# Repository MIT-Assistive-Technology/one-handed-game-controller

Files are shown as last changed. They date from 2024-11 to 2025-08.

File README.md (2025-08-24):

# :video_game: **One-Handed Game Controller (Left-Handed)**

## :memo: **Instructions Overview**

⭐ **Please refer to [this handout](https://docs.google.com/document/d/1R1JeNCjT1L_K-hidx_33zdM9vNTuleeNFn41tkV1ZXg/edit?usp=sharing) for detailed instructions and materials.**

1. Download files
2. 3D print files
4. Print/Order PCBs
5. Solder Electronic Components
6. Upload code to the Arduino
7. Assemble

## :mag_right: Problem Statement
**Modern game controllers do not accommodate for one-handed users.**

After a stroke or injury, a person may lose some function in their body. Recreational products for the public are often made with the assumption that a person has full control of their body, which means that after permanent injuries, a person may become limited in their choice of hobbies.

Our codesigner, Susan Bibbins, suffers from chronic pain from fibromyalgia and has limited function in her right hand. She always wanted to play video games; however, modern controllers do not accomodate one-handed users.

Our team aims to develop a comfortable and accessible game controller designed specifically for one-handed users so that our codesigner can finally play video games that she has always wanted to try.

## 🔗 References




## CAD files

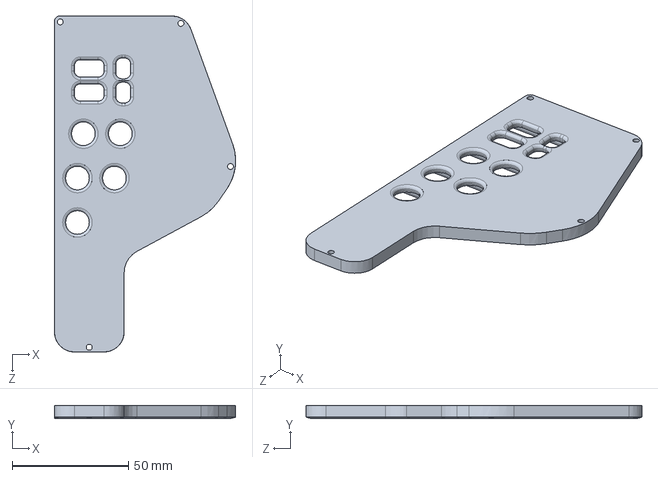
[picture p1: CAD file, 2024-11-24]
CADs/Base/back_face.SLDPRT
77.8 x 5.71 x 144.3 mm

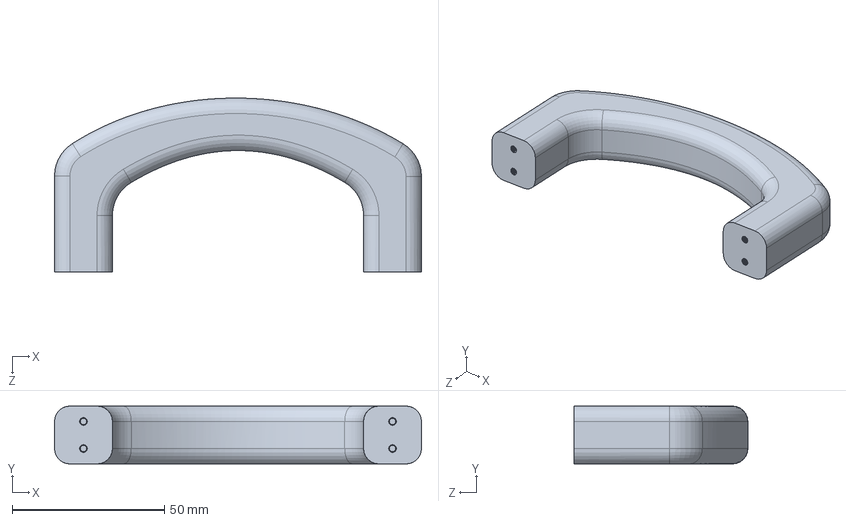
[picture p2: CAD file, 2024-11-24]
CADs/Handle/handle.SLDPRT
120.7 x 19.1 x 57.1 mm

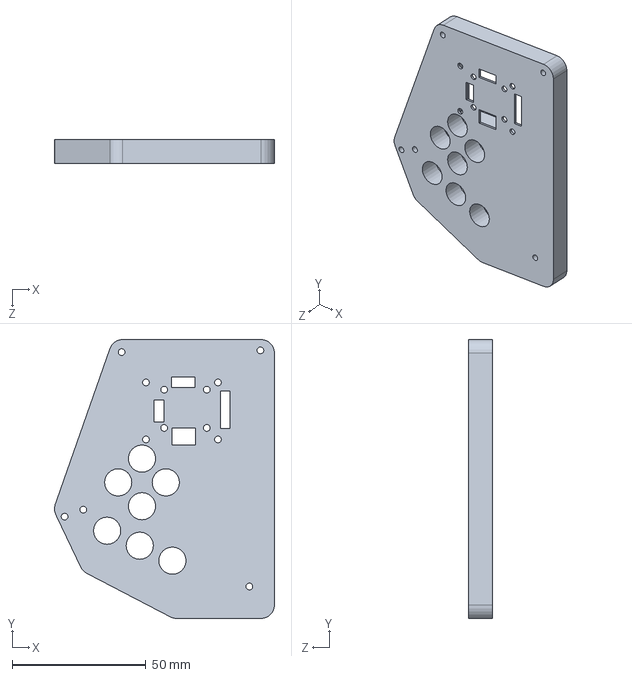
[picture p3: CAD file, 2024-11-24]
CADs/Mounts/f_front_pcb_mount.SLDPRT
82.1 x 104.1 x 8.89 mm

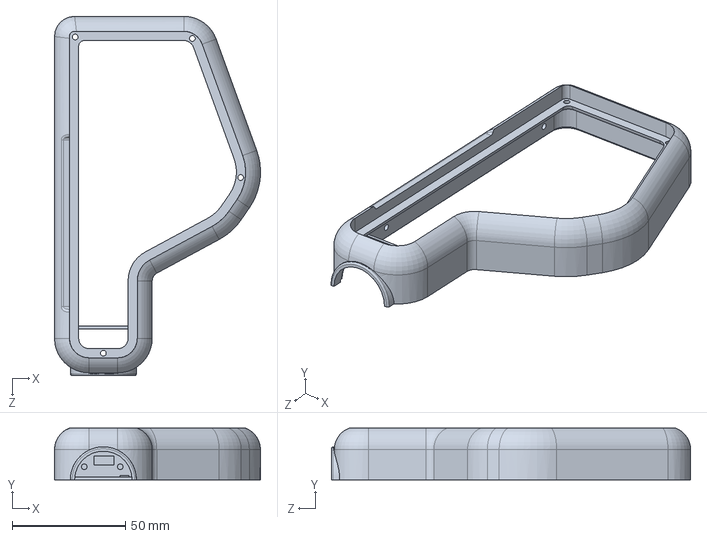
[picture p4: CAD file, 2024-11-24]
CADs/Base/front_side.SLDPRT
91.0 x 22.9 x 158.8 mm

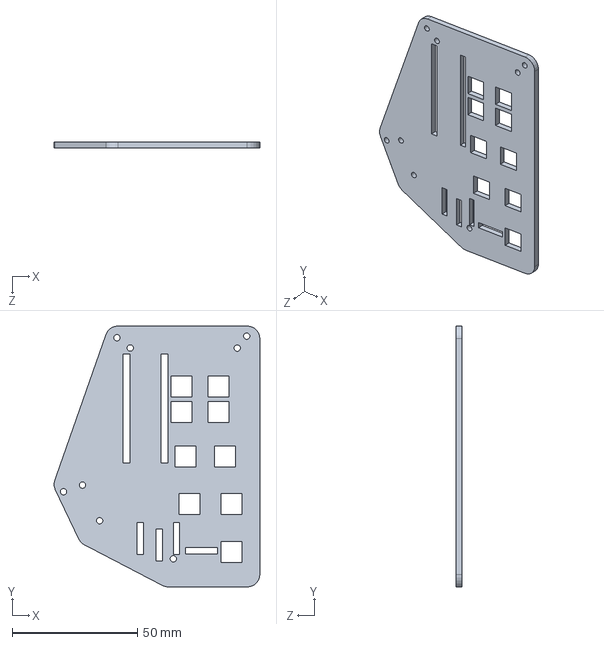
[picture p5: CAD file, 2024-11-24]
CADs/Mounts/b_back_pcb_mount.SLDPRT
82.1 x 104.1 x 2.54 mm

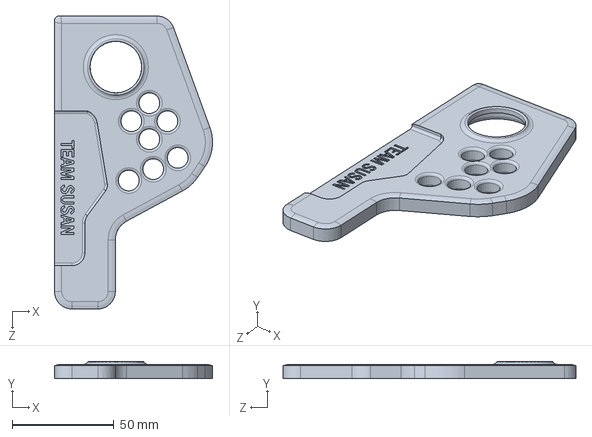
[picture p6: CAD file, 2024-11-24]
CADs/Base/front_face.SLDPRT
77.8 x 8.45 x 144.3 mm

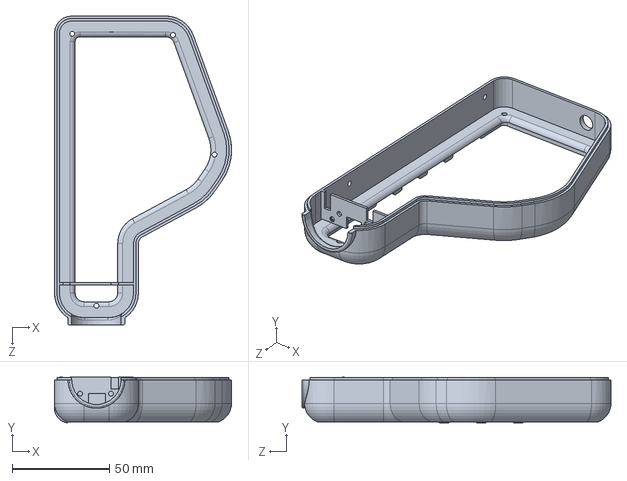
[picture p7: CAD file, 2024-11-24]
CADs/Base/back_side.SLDPRT
91.0 x 23.6 x 158.8 mm

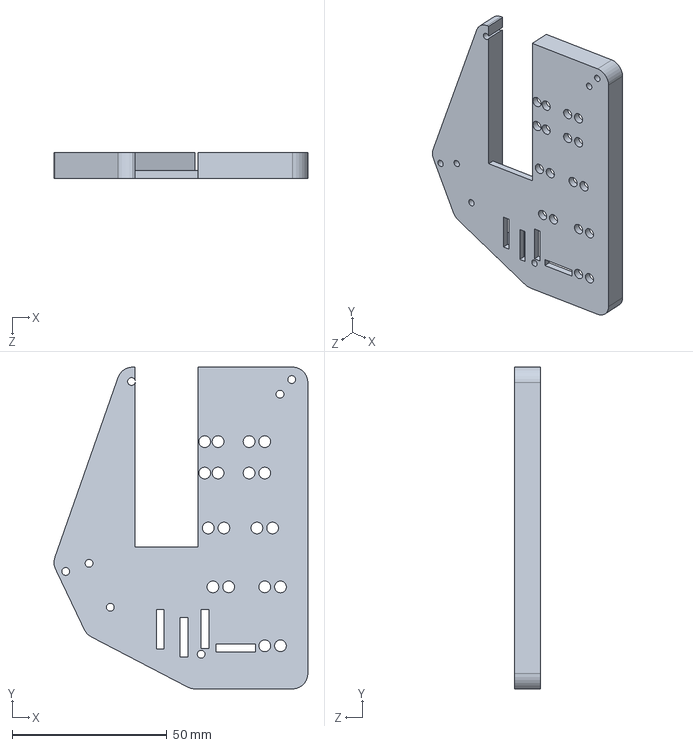
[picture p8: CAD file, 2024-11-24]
CADs/Mounts/b_front_pcb_mount.SLDPRT
82.1 x 104.1 x 8.38 mm

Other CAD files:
CADs/Mounts/f_back_pcb_mount.SLDPRT

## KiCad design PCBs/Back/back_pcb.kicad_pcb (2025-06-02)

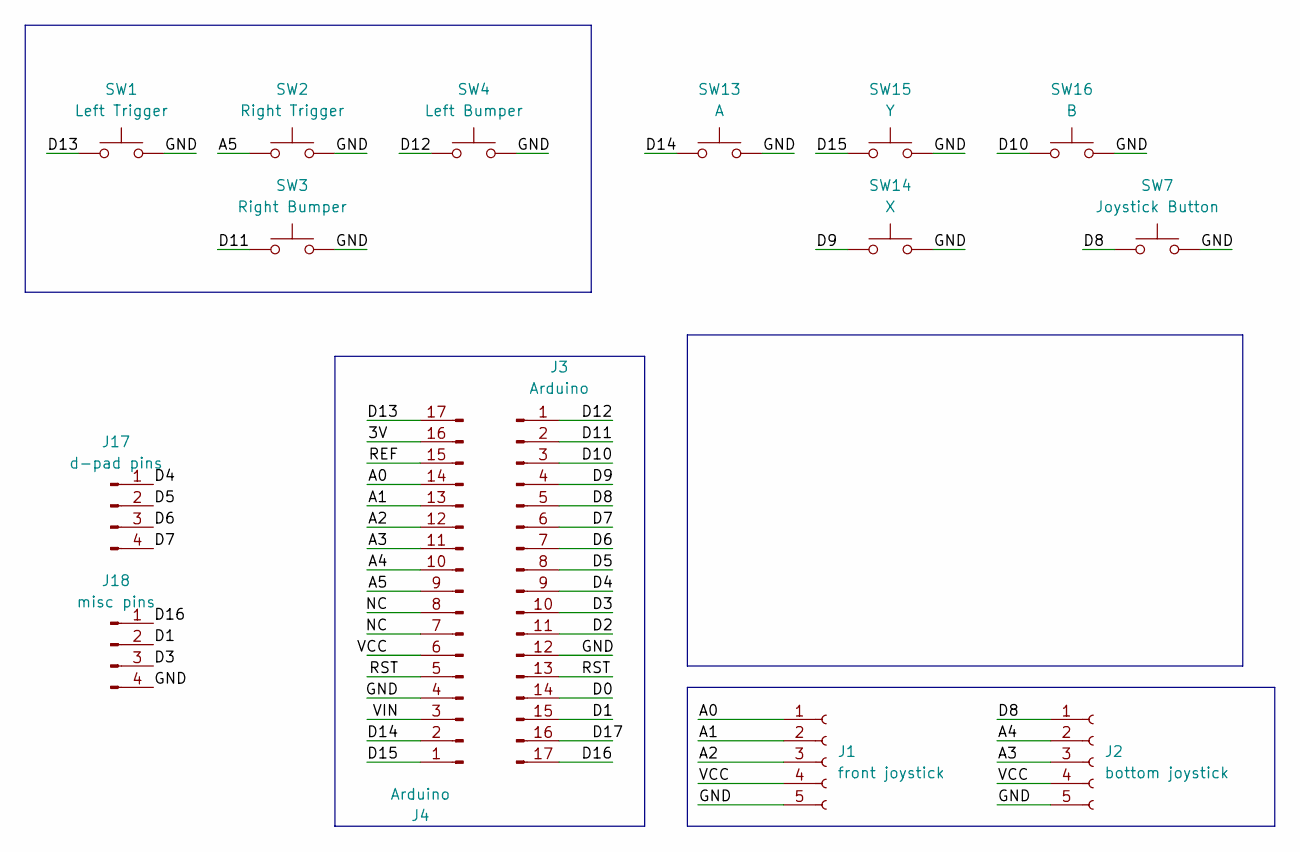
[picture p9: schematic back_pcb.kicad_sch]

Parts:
J1: front joystick; PinSocket_1x05_P2.54mm_Vertical
J2: bottom joystick; PinSocket_1x05_P2.54mm_Vertical
J3, J4: Arduino; PinSocket_1x17_P2.54mm_Vertical
J17: d-pad pins; PinSocket_1x04_P2.54mm_Vertical
J18: misc pins; PinSocket_1x04_P2.54mm_Vertical
SW1: Left Trigger; SW_BUTT-2
SW2: Right Trigger; SW_BUTT-2
SW3: Right Bumper; SW_BUTT-2
SW4: Left Bumper; SW_BUTT-2
SW7: Joystick Button; SW_BUTT-2
SW13: A; SW_BUTT-2
SW14: X; SW_BUTT-2
SW15: Y; SW_BUTT-2
SW16: B; SW_BUTT-2

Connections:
/3V: J4.16
/A0: J1.1, J4.14
/A1: J1.2, J4.13
/A2: J1.3, J4.12
/A3: J2.3, J4.11
/A4: J2.2, J4.10
/A5: J4.9, SW2.1
/D0: J3.14
/D1: J3.15, J18.2
/D2: J3.11
/D3: J3.10, J18.3
/D4: J3.9, J17.1
/D5: J3.8, J17.2
/D6: J3.7, J17.3
/D7: J3.6, J17.4
/D8: J2.1, J3.5, SW7.1
/D9: J3.4, SW14.1
/D10: J3.3, SW16.1
/D11: J3.2, SW3.1
/D12: J3.1, SW4.1
/D13: J4.17, SW1.1
/D14: J4.2, SW13.1
/D15: J4.1, SW15.1
/D16: J3.17, J18.1
/D17: J3.16
/GND: J1.5, J2.5, J3.12, J4.4, J18.4, SW1.2, SW2.2, SW3.2, SW4.2, SW7.2, SW13.2, SW14.2, SW15.2, SW16.2
/NC: J4.7, J4.8
/REF: J4.15
/RST: J3.13, J4.5
/VCC: J1.4, J2.4, J4.6
/VIN: J4.3

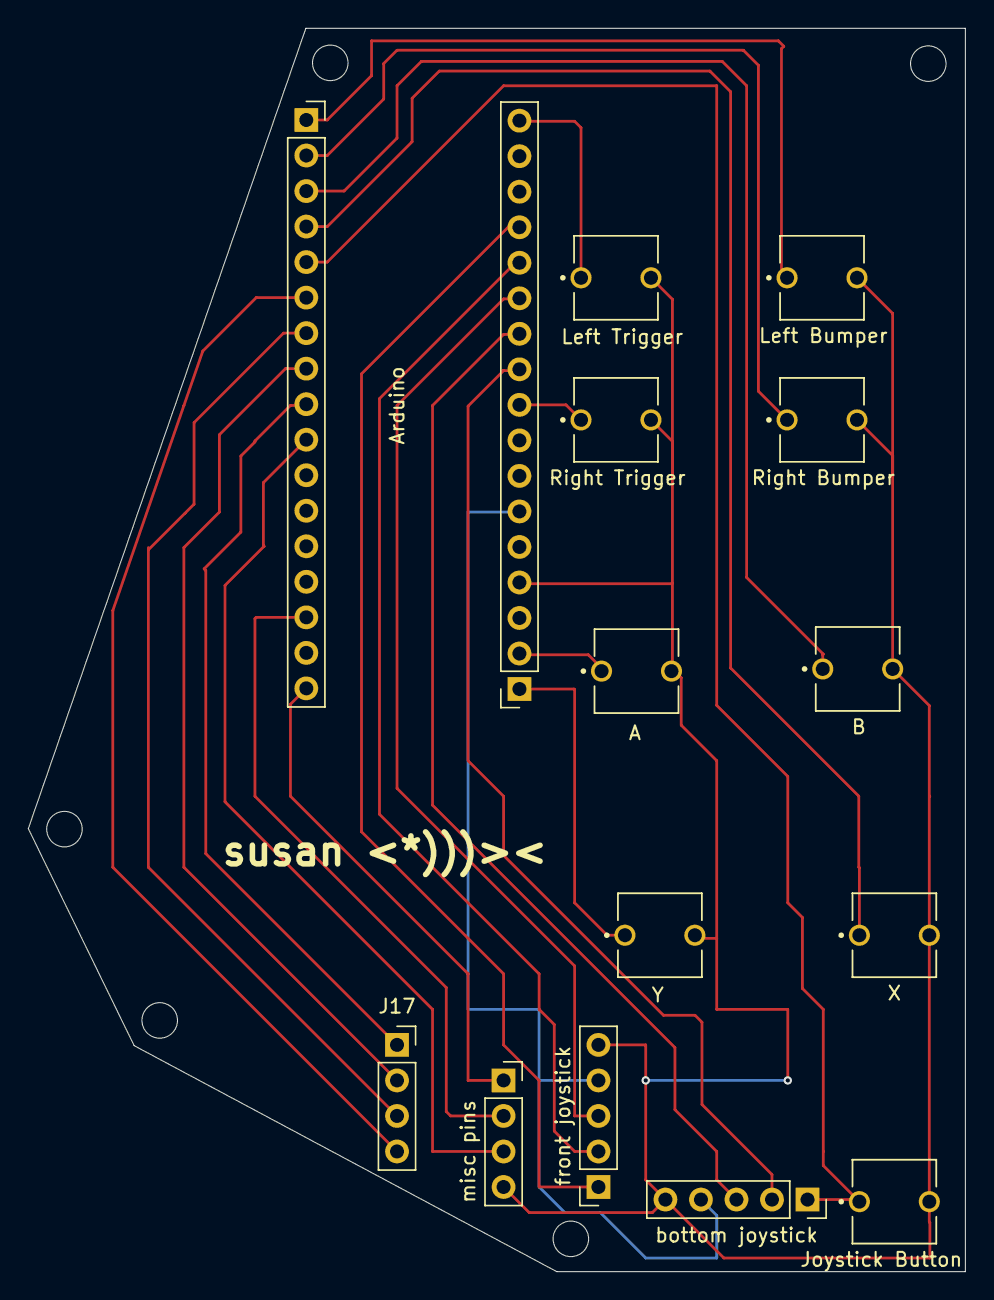
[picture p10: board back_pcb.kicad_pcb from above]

Board: 2 copper layers, 67.0 x 88.9 mm, 15 parts (0 on the bottom side), 25 nets.

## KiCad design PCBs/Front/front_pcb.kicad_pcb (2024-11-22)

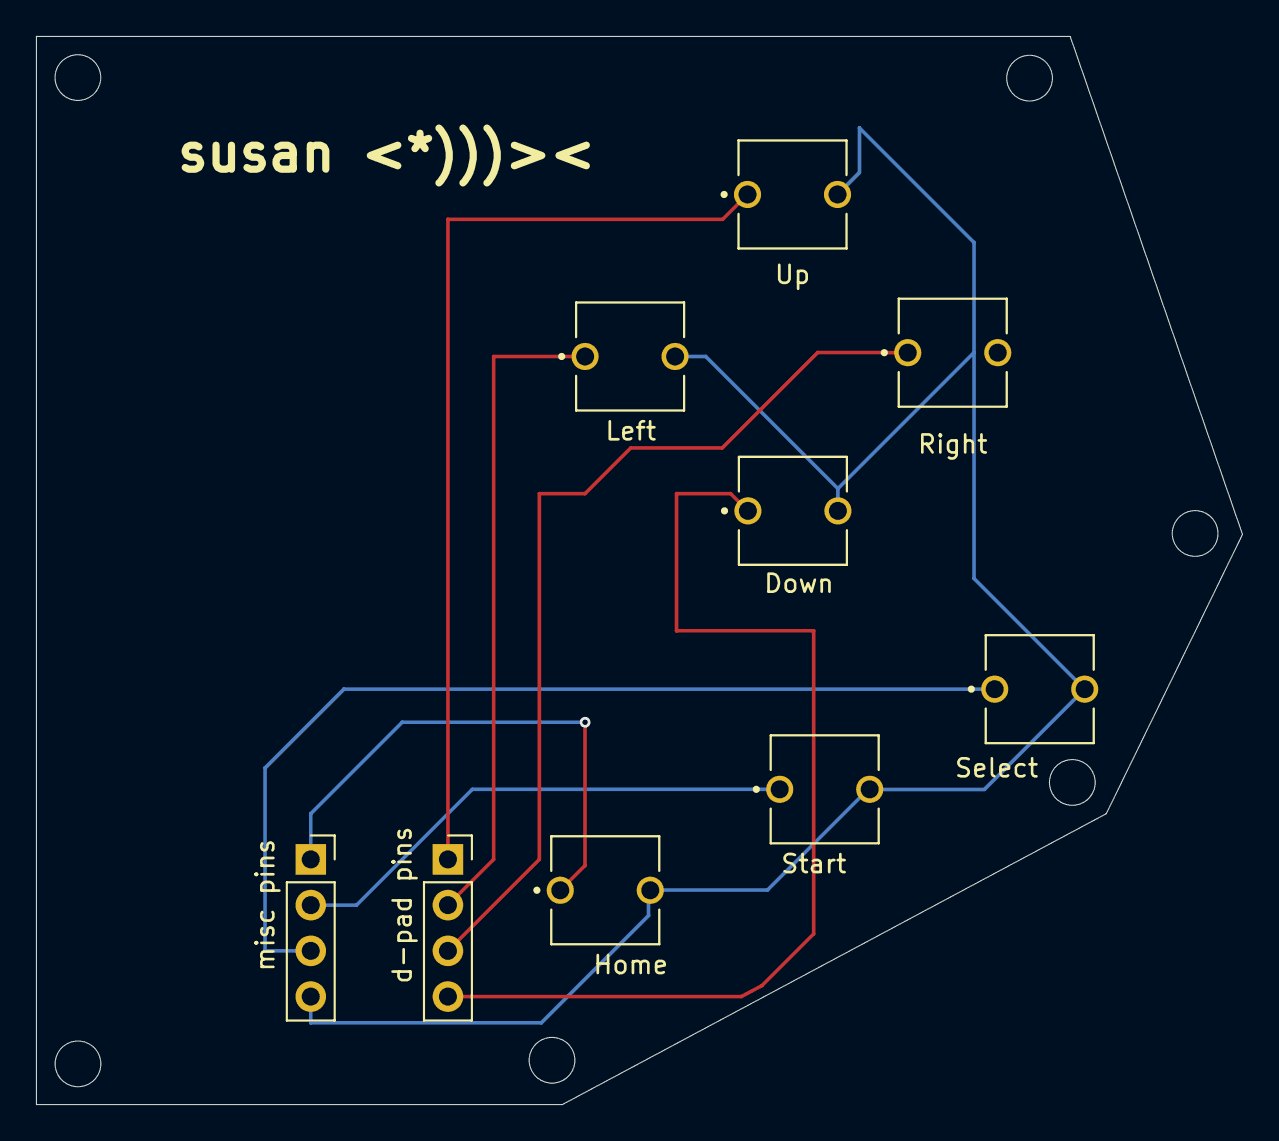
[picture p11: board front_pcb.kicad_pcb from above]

Board: 2 copper layers, 67.0 x 59.3 mm, 9 parts (0 on the bottom side), 8 nets.

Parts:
J1: d-pad pins; PinSocket_1x04_P2.54mm_Vertical
J2: misc pins; PinSocket_1x04_P2.54mm_Vertical
SW1: Up; SW_BUTT-2
SW2: Down; SW_BUTT-2
SW3: Left; SW_BUTT-2
SW4: Right; SW_BUTT-2
SW6: Home; SW_BUTT-2
SW7: Start; SW_BUTT-2
SW8: Select; SW_BUTT-2

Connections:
/D0: J1.1, SW1.1
/D1: J2.3, SW8.1
/D2: J1.2, SW3.1
/D3: J1.3, SW4.1
/D4: J1.4, SW2.1
/D16: J2.1, SW6.1
/D17: J2.2, SW7.1
/GND: J2.4, SW1.2, SW2.2, SW3.2, SW4.2, SW6.2, SW7.2, SW8.2

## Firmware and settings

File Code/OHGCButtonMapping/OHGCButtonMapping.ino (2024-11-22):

/*
 *  Project     Arduino XInput Library
 *  @author     David Madison
 *  @link       github.com/dmadison/ArduinoXInput
 *  @license    MIT - Copyright (c) 2019 David Madison
 *
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
 *  Example:      GamepadPins
 *  Description:  Uses all of the available pin inputs to build a 'complete'
 *                Xbox gamepad, with both analog joysticks, both triggers,
 *                and all of the main buttons.
 *
 *                * Joysticks should be your typical 10k dual potentiometers.
 *                  To prevent random values caused by floating inputs,
                    joysticks are disabled by default.
 *                * Triggers can be either analog (pots) or digital (buttons).
 *                  Set the 'TriggerButtons' variable to change between the two.
 *                * Buttons use the internal pull-ups and should be connected
 *                  directly to ground.
 *
 *                These pins are designed around the Leonardo's layout. You
 *                may need to change the pin numbers if you're using a
 *                different board type
 *
 */

#include <XInput.h>

// Setup
const boolean UseLeftJoystick   = true;  // set to true to enable left joystick
const boolean InvertLeftYAxis   = false;  // set to true to use inverted left joy Y

const boolean UseRightJoystick  = true;  // set to true to enable right joystick
const boolean InvertRightYAxis  = false;  // set to true to use inverted right joy Y

const boolean UseTriggerButtons = true;   // set to false if using analog triggers

const int ADC_Max = 1023/2;  // 10 bit

// Joystick Pins
const int Pin_LeftJoyX  = A2;
const int Pin_LeftJoyY  = A1;
const int Pin_RightJoyX = A3;
const int Pin_RightJoyY = A4;

// Trigger Pins
const int Pin_TriggerL = 13;
const int Pin_TriggerR = A5;

// Button Pins
const int Pin_ButtonA = 14;
const int Pin_ButtonB = 10;
const int Pin_ButtonX = 9;
const int Pin_ButtonY = 15;

const int Pin_ButtonLB = 12;
const int Pin_ButtonRB = 11;

const int Pin_ButtonBack = 3;
const int Pin_ButtonStart = 1;
const int Pin_ButtonLogo = 16;

// Joystick Buttons
const int Pin_ButtonL3 = A0;
const int Pin_ButtonR3 = 8;

// Directional Pad Pins
const int Pin_DpadUp    = 4;
const int Pin_DpadDown  = 7;
const int Pin_DpadLeft  = 5;
const int Pin_DpadRight = 6;

void setup() {
	// If using buttons for the triggers, use internal pull-up resistors
	if (UseTriggerButtons == true) {
		pinMode(Pin_TriggerL, INPUT_PULLUP);
		pinMode(Pin_TriggerR, INPUT_PULLUP);
	}
	// If using potentiometers for the triggers, set range
	else {
		XInput.setTriggerRange(0, ADC_Max);
	}

	// Set buttons as inputs, using internal pull-up resistors
	pinMode(Pin_ButtonA, INPUT_PULLUP);
	pinMode(Pin_ButtonB, INPUT_PULLUP);
	pinMode(Pin_ButtonX, INPUT_PULLUP);
	pinMode(Pin_ButtonY, INPUT_PULLUP);

	pinMode(Pin_ButtonLB, INPUT_PULLUP);
	pinMode(Pin_ButtonRB, INPUT_PULLUP);

	pinMode(Pin_ButtonBack, INPUT_PULLUP);
	pinMode(Pin_ButtonStart, INPUT_PULLUP);
  pinMode(Pin_ButtonLogo, INPUT_PULLUP);

	pinMode(Pin_ButtonL3, INPUT_PULLUP);
	pinMode(Pin_ButtonR3, INPUT_PULLUP);

	pinMode(Pin_DpadUp, INPUT_PULLUP);
	pinMode(Pin_DpadDown, INPUT_PULLUP);
	pinMode(Pin_DpadLeft, INPUT_PULLUP);
	pinMode(Pin_DpadRight, INPUT_PULLUP);

	XInput.setJoystickRange(0, ADC_Max);  // Set joystick range to the ADC
	XInput.setAutoSend(false);  // Wait for all controls before sending

	XInput.begin();
}

void loop() {
	// Read pin values and store in variables
	// (Note the "!" to invert the state, because LOW = pressed)
	boolean buttonA = !digitalRead(Pin_ButtonA);
	boolean buttonB = !digitalRead(Pin_ButtonB);
	boolean buttonX = !digitalRead(Pin_ButtonX);
	boolean buttonY = !digitalRead(Pin_ButtonY);

	boolean buttonLB = !digitalRead(Pin_ButtonLB);
	boolean buttonRB = !digitalRead(Pin_ButtonRB);

	boolean buttonBack  = !digitalRead(Pin_ButtonBack);
	boolean buttonStart = !digitalRead(Pin_ButtonStart);
  boolean buttonLogo  = !digitalRead(Pin_ButtonLogo);

	boolean buttonL3 = !digitalRead(Pin_ButtonL3);
	boolean buttonR3 = !digitalRead(Pin_ButtonR3);

	boolean dpadUp    = !digitalRead(Pin_DpadUp);
	boolean dpadDown  = !digitalRead(Pin_DpadDown);
	boolean dpadLeft  = !digitalRead(Pin_DpadLeft);
	boolean dpadRight = !digitalRead(Pin_DpadRight);

	// Set XInput buttons
	XInput.setButton(BUTTON_A, buttonA);
	XInput.setButton(BUTTON_B, buttonB);
	XInput.setButton(BUTTON_X, buttonX);
	XInput.setButton(BUTTON_Y, buttonY);

	XInput.setButton(BUTTON_LB, buttonLB);
	XInput.setButton(BUTTON_RB, buttonRB);

	XInput.setButton(BUTTON_BACK, buttonBack);
	XInput.setButton(BUTTON_START, buttonStart);
  XInput.setButton(BUTTON_LOGO, buttonLogo);

	XInput.setButton(BUTTON_L3, buttonL3);
	XInput.setButton(BUTTON_R3, buttonR3);

	// Set XInput DPAD values
	XInput.setDpad(dpadUp, dpadDown, dpadLeft, dpadRight);

	// Set XInput trigger values
	if (UseTriggerButtons == true) {
		// Read trigger buttons
		boolean triggerLeft  = !digitalRead(Pin_TriggerL);
		boolean triggerRight = !digitalRead(Pin_TriggerR);

		// Set the triggers as if they were buttons
		XInput.setButton(TRIGGER_LEFT, triggerLeft);
		XInput.setButton(TRIGGER_RIGHT, triggerRight);
	}
	else {
		// Read trigger potentiometer values
		int triggerLeft  = analogRead(Pin_TriggerL);
		int triggerRight = analogRead(Pin_TriggerR);

		// Set the trigger values as analog
		XInput.setTrigger(TRIGGER_LEFT, triggerLeft);
		XInput.setTrigger(TRIGGER_RIGHT, triggerRight);
	}

	// Set left joystick
	if (UseLeftJoystick == true) {
		int leftJoyX = analogRead(Pin_LeftJoyX);
		int leftJoyY = analogRead(Pin_LeftJoyY);

		// White lie here... most generic joysticks are typically
		// inverted by default. If the "Invert" variable is false
		// then we'll take the opposite value with 'not' (!).
		boolean invert = !InvertLeftYAxis;

		XInput.setJoystickX(JOY_LEFT, leftJoyX-256.1);
		XInput.setJoystickY(JOY_LEFT, leftJoyY-250.8, invert);
	}

	// Set right joystick
	if (UseRightJoystick == true) {
		int rightJoyX = analogRead(Pin_RightJoyX);
		int rightJoyY = analogRead(Pin_RightJoyY);

		boolean invert = !InvertRightYAxis;

		XInput.setJoystickX(JOY_RIGHT, rightJoyX-248.2);
		XInput.setJoystickY(JOY_RIGHT, rightJoyY-260.5, invert);
	}

	// Send control data to the computer
	XInput.send();
}

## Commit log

2024-11-22 :sparkles: add PCBs
    - front PCB
    - back PCB
    [back_pcb.kicad_pcb, back_pcb.kicad_sch, front_pcb.kicad_pcb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]
2024-11-22 :construction: add arduino code
    - code for arduino
2024-11-24 :sparkles: add base CADs
    - back face
    - backside
    - front face
    - front side
    [back_face.SLDPRT, back_side.SLDPRT, front_face.SLDPRT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]
2024-11-24 :sparkles: add handle CAD
    - handle
    [handle.SLDPRT]
2024-11-24 :sparkles: add mount CADs
    - 2 back PCB mounts
    - 2 front PCB mounts
    [B_Back_Mount_v4.SLDPRT, B_Front_Mount_v4.SLDPRT, F_Back_Mount_v4.SLDPRT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]
2024-11-24 :truck: rename mounts
    [b_back_pcb_mount.SLDPRT, b_front_pcb_mount.SLDPRT, f_back_pcb_mount.SLDPRT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]
2025-06-02 🐛 add missing gnd connection
    - missing gnd connection to the misc pins
    [back_pcb.kicad_pcb]
2025-08-24 ✨ add instruction document
2025-08-24 🐛 fix link
